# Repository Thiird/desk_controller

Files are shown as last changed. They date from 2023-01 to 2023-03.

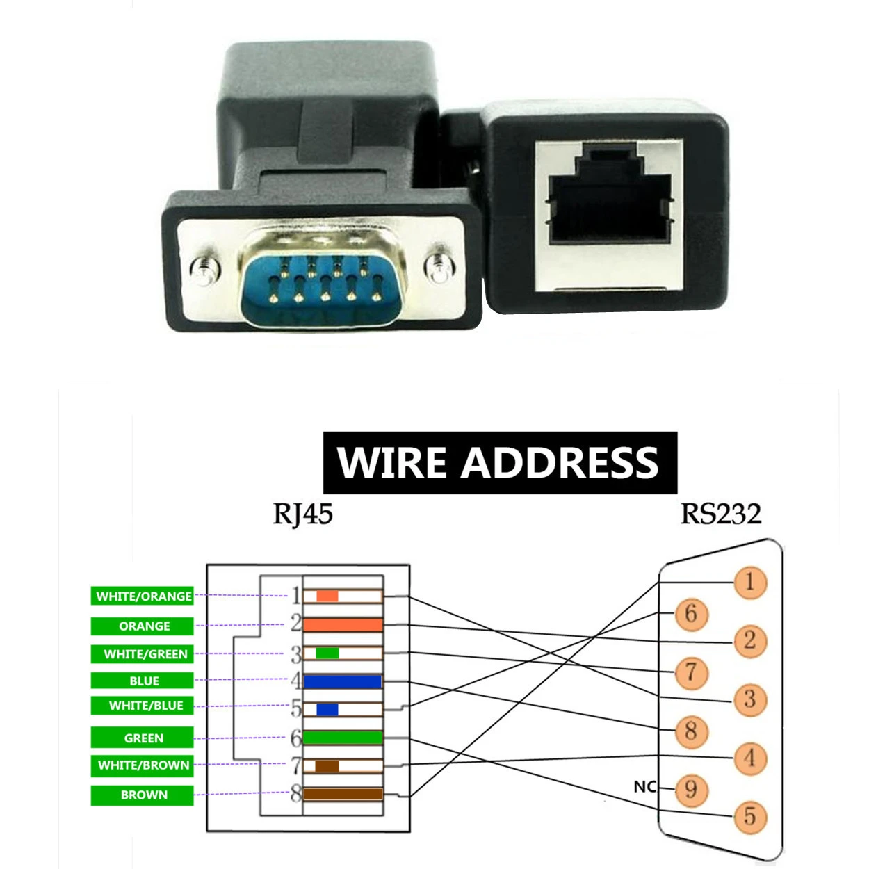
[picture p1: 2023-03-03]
documentation/RJ45-a-9-pin-adattatore-femmina-RJ45-a-DB9pin-maschio-DB9-femmina-RJ45-a-porta-di.jpg_Q90.jpg_.webp

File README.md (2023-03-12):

# Desk Controller

Desk controller is a gadget that connects to my pc and can:
- power on/off the pc
- reset the pc
- select the booting OS
- control a bias lighting system
- control a desk led strip

The power on/off functionality is achieved by shorting the two respective pc signals to pc ground via optocouplers.

The booting OS selection is done by interacting with GRUB via serial port.

The bias lighting is the most complex part of this whole system.
The setup consists of a WS2815 12V led strip mounted around my main monitor, which is controlled by the STM32C0 of the desk controller by bit-banging the RGB data.
The RGB data is computed by a Visual C++ application running on windows and sent to the desk controller via serial port.
The main challenge here was to make a fast enough algorithm to to compute the RGB data, for the bias lighting to be reactive I wanted to achieve a 30Hz refresh rate of the RGB data, which means updating the leds color at most every 0.33.. seconds.
Without getting into GPU shaders and such, the wastest way to capture a screenshot of the screen and calculate the average color for the sections of the screen around the border, was to use the Desktop Duplication Windows API.

I inted too use this feature only during gaming or watching films, which I only do on windows. A Linux-equivalent application can always be made at a later moment,

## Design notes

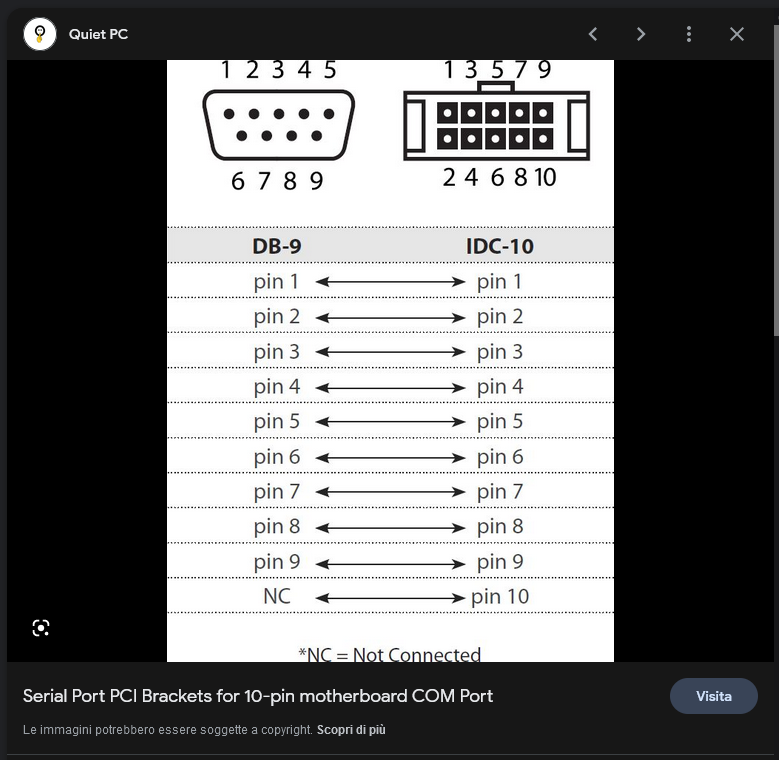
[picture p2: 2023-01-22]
documentation/db9_pinout.png

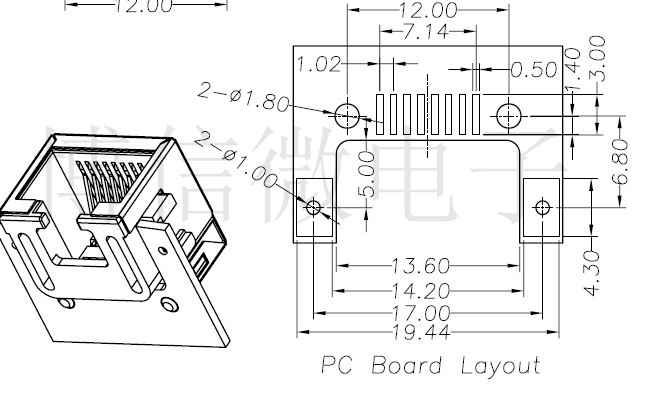
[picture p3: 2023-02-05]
documentation/HTB1GY2Ra5jrK1RjSsplq6xHmVXaq.jpg

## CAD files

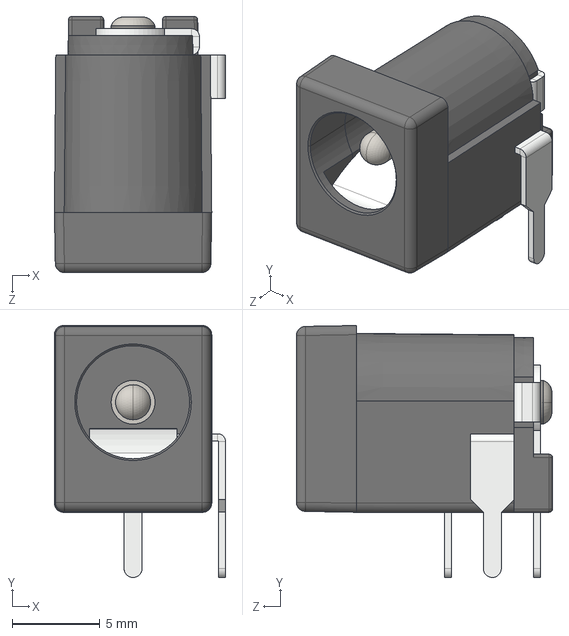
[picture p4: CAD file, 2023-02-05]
HW/local_libraries/DC Power Jack 5.5mm x 2.1mm.STEP
9.77 x 14.4 x 14.6 mm

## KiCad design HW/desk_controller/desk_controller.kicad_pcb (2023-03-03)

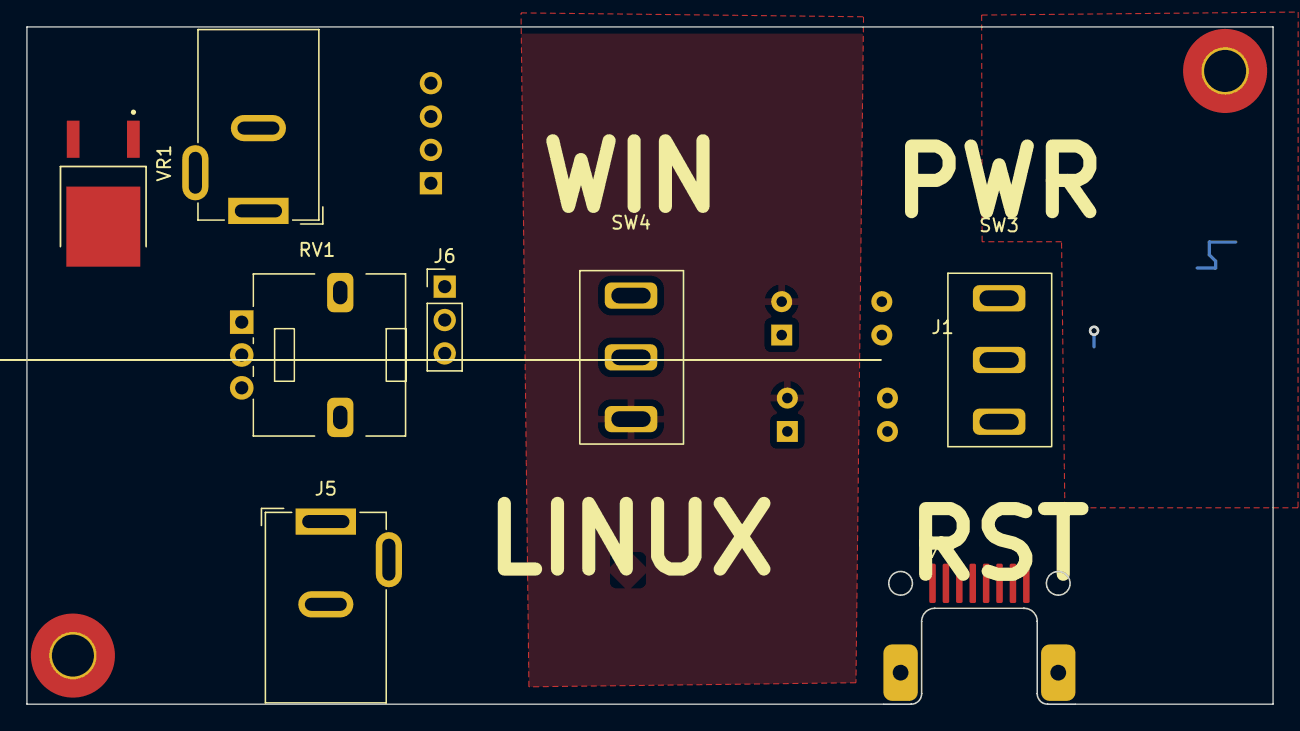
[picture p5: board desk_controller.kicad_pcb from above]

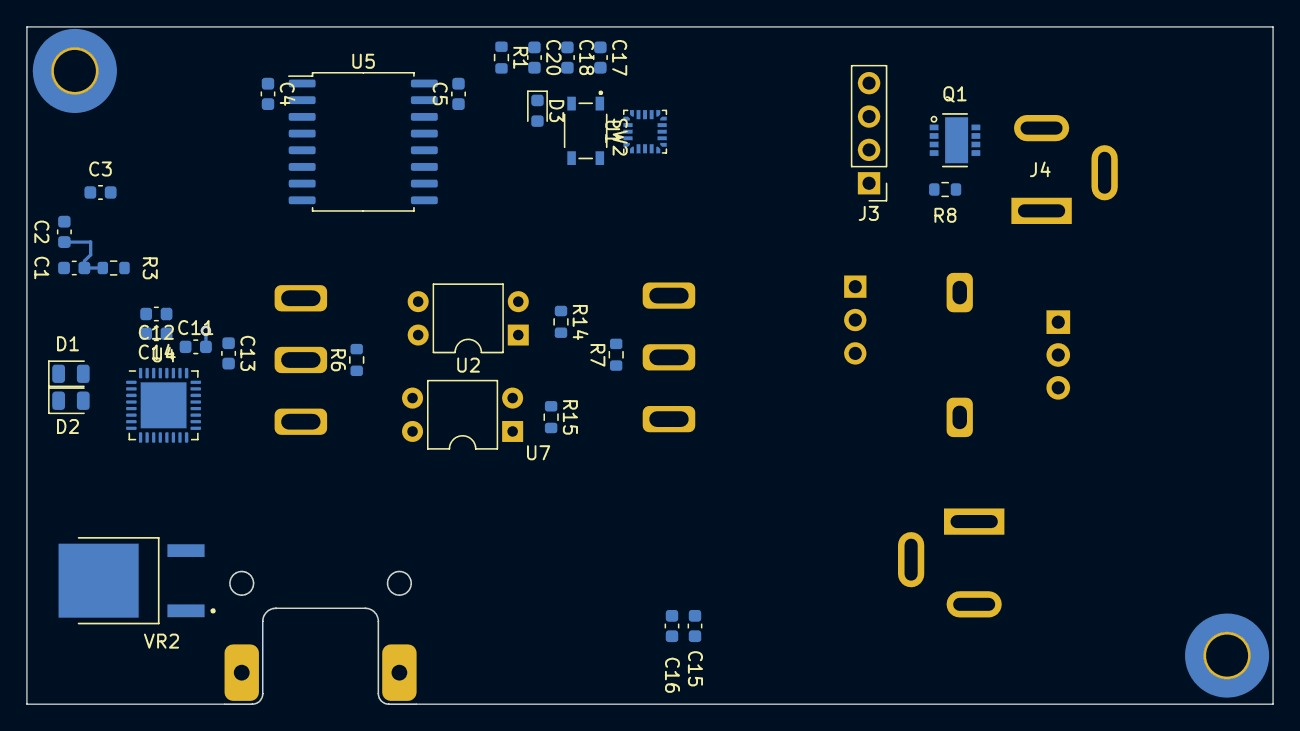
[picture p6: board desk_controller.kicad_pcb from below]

Board: 2 copper layers, 94.9 x 51.6 mm, 43 parts (33 on the bottom side), 36 nets.

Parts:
C1: DNP; C_0603_1608Metric
C2: 330n; C_0603_1608Metric
C3, C4, C5, C11, C12, C13, C14, C17, C18: 100n; C_0603_1608Metric
C15, C16: C; C_0603_1608Metric
C20: 4u7; C_0603_1608Metric
D1, D2: D_Schottky; D_0805_2012Metric
D3: RED; LED_0603_1608Metric
H1, H2: MountingHole; MountingHole_3.2mm_M3_Pad_TopBottom
J1: RJ45; RJ45_midplane
J3: SWD_header; PinHeader_1x04_P2.54mm_Vertical
J4, J5: Barrel_Jack_MountingPin; BarrelJack_GCT_DCJ200-10-A_Horizontal
J6: debug_uart; PinHeader_1x03_P2.54mm_Vertical
Q1: RQ3E110AJ; SOTFL65P330X80-8N
R1: 3k3; R_0603_1608Metric
R3, R6, R7: 1k; R_0603_1608Metric
R8: 10k; R_0603_1608Metric
R14, R15: R; R_0603_1608Metric
RV1: R_Potentiometer; Potentiometer_Alps_RK09L_Single_Vertical
SW2: SW_Push_Open_Dual; SW_SKRPACE010
SW3: PC_PWR_RST_SW; MTS-102-103
SW4: OS_SW; MTS-102-103
U1: STM32C011F4Ux; ST_UFQFPN-20_3x3mm_P0.5mm
U2, U7: PC817; DIP-4_W7.62mm
U4: TRS3243ECRHBR; VQFN-32-1EP_5x5mm_P0.5mm_EP3.5x3.5mm
U5: ISO7341FC; SOIC-16W_7.5x10.3mm_P1.27mm
VR1, VR2: UA78M33CKVURG3; TO229P990X252-3N

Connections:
+3.3V: C5.2, C15.1, U5.10 (EN2), U5.16 (VCC2), VR1.3 (OUT)
+3V3: C17.1, C20.1, J3.1, SW3.1, SW4.1, U1.2 (VDD)
+12V: C16.1, J4.1, J5.1, VR1.1 (IN)
/mcu/NRST: C18.1, SW2.1, SW2.2, U1.4 (PF2)
/rs232/232_DTR: D1.2 (A), J1.6, U4.2 (RIN2)
/rs232/232_RTS: D2.2 (A), J1.7, U4.3 (RIN3)
/rs232/232_RX: J1.5, U4.6 (DOUT1)
/rs232/232_TX: J1.4, U4.1 (RIN1)
/rs232/232_VCC_3V3: C3.1, C4.1, C11.1, U4.26 (VCC), U5.1 (VCC1), U5.7 (EN1), VR2.3 (OUT)
/rs232/232_VUR: C1.1, C2.1, R3.1, VR2.1 (IN)
/rs232/TTL_DTR: U4.17 (ROUT2), U5.4 (INB)
/rs232/TTL_RTS: U4.15 (ROUT3), U5.5 (INC)
/rs232/TTL_RX: U4.12 (DIN1), U5.6 (OUTD)
/rs232/TTL_TX: U4.18 (ROUT1), U5.3 (INA)
GND: C5.1, C15.2, C16.2, C17.2, C18.2, C20.2, D3.1 (K), J3.4, J5.2, J6.3, Q1.1 (S), R8.2, SW2.3, SW2.4, SW3.3, SW4.3, U1.3 (VSS), U2.2, U5.9 (GND2), U5.15 (GND2), U7.2, VR1.4 (GND)
GND1: C1.2, C2.2, C3.2, C4.2, C11.2, J1.8, U4.24 (GND), U5.2 (GND1), U5.8 (GND1), VR2.4 (GND)
unnamed: D1.1 (K), D2.1 (K), R3.2
unnamed: D3.2 (A), R1.2
unnamed: J4.2, Q1.3 (D)
unnamed: R6.2, SW3.2
unnamed: R7.2, SW4.2
unnamed: R14.2, U2.1
unnamed: R15.2, U7.1
unnamed: R1.1, U1.19 (PB7)
unnamed: C13.1, U4.28 (C1+)
unnamed: C13.2, U4.23 (C1-)
unnamed: C14.1, U4.29 (C2+)
unnamed: C14.2, U4.30 (C2-)
unnamed: C12.1, U4.27 (V+)
unnamed: C12.2, U4.31 (V-)
PC_GND: J1.3, U2.3, U7.3
PC_POWER: J1.1, U2.4
PC_RESET: J1.2, U7.4
TTL_RX_ISO: U1.15 (PA10/PA12), U5.11 (IND)
TTL_TX_ISO: U1.14 (PA9/PA11), U5.14 (OUTA)
mosfet_gate: Q1.2 (G), R8.1

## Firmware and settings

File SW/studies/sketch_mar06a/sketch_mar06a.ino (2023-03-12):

const int BUTTON_PIN = 2;        // the number of the pushbutton pin
const int DEBOUNCE_DELAY = 50;   // the debounce time; increase if the output flickers

int lastSteadyState = LOW;       // the previous steady state from the input pin
int lastFlickerableState = LOW;  // the previous flickerable state from the input pin
int currentState;                // the current reading from the input pin

unsigned long lastDebounceTime = 0;  // the last time the output pin was toggled

void setup() {
  Serial.begin(115200, SERIAL_8N1);
  Serial1.begin(115200, SERIAL_8N1);
  pinMode(BUTTON_PIN, INPUT_PULLUP);
}

void loop() {
  currentState = digitalRead(BUTTON_PIN);
  if (currentState != lastFlickerableState) {
    lastDebounceTime = millis();
    lastFlickerableState = currentState;
  }

  if ((millis() - lastDebounceTime) > DEBOUNCE_DELAY) {
    if (lastSteadyState == HIGH && currentState == LOW)
    {      
      Serial1.write("Bias_ON\n");
    }
    else if (lastSteadyState == LOW && currentState == HIGH)
    {
      Serial1.write("Bias_OFF\n");
    }

    // save the the last steady state
    lastSteadyState = currentState;
  }

  while(Serial1.available())
  {
    Serial.write(Serial1.read());
  }
}

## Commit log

2023-01-22 Some work
    [desk_controller.kicad_sch]
2023-01-22 Sch work
    [desk_controller.kicad_sch]
2023-01-23 Added sheets in sch, added TI document for isolated rs232 interface with power harvesting, general sch work
    [desk_controller.kicad_sch, mcu.kicad_sch, power_input.kicad_sch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]
2023-01-25 Added components
    [desk_controller.kicad_sch, mcu.kicad_sch, rs232.kicad_sch]
2023-01-26 Buck converter sch, rs232 transceiver
    [desk_controller.kicad_sch, mcu.kicad_sch, power_input.kicad_sch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]
2023-01-27 Sch fixes, initial board layout
    [IRM-60.stp, desk_controller.kicad_pcb, desk_controller.kicad_sch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]
2023-01-28 Removed acdc brick
    [desk_controller.kicad_pcb, desk_controller.kicad_sch, mcu.kicad_sch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]
2023-02-05 Much progress in sch and brd
    [DC Power Jack 5.5mm x 2.1mm.STEP, IRM-60.stp, desk_controller.kicad_pcb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]
2023-03-03 moved to kicad 7, sch work
    [desk_controller.kicad_pcb, desk_controller.kicad_sch]
2023-03-12 Added README, high level folders, working example of bias lighting calculator
    [DC Power Jack 5.5mm x 2.1mm.STEP, desk_controller.kicad_pcb, desk_controller.kicad_sch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]
